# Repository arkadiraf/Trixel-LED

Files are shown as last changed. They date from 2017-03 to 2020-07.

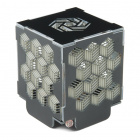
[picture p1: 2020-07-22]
Bootloader/SparkFun ISP Pogo Adapter - KIT-11591 - SparkFun Electronics_files/14638-Night_Light_Soldering_Kit-Built_.jpg

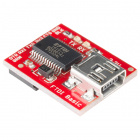
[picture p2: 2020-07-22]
Bootloader/SparkFun ISP Pogo Adapter - KIT-11591 - SparkFun Electronics_files/09873-01a.jpg

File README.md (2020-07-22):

# Trixel-LED
Trixel LED is an interactive LED kit,
Create your own interactive Light elements by soldering basic shapes, such as triangle, square, pentagon and Hexagon. to create an interactive LED sculpture.

### [Trixel LED on Hackaday](https://hackaday.io/project/20510-trixel-led)

<br /><span xmlns:dct="http://purl.org/dc/terms/" property="dct:title">Trixel-LED</span> is licensed under a <a rel="license" href="http://creativecommons.org/licenses/by-nc-sa/4.0/">Creative Commons Attribution-NonCommercial-ShareAlike 4.0 International License</a>.

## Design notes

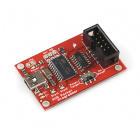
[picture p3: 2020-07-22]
Bootloader/SparkFun ISP Pogo Adapter - KIT-11591 - SparkFun Electronics_files/09825-01b.jpg

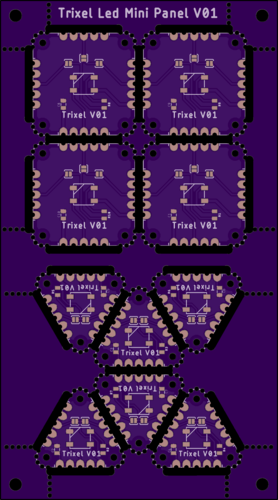
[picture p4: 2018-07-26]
Eagle/Single Side/Paneling/MiniPanel V01/design versions - temp/Top_V3.png

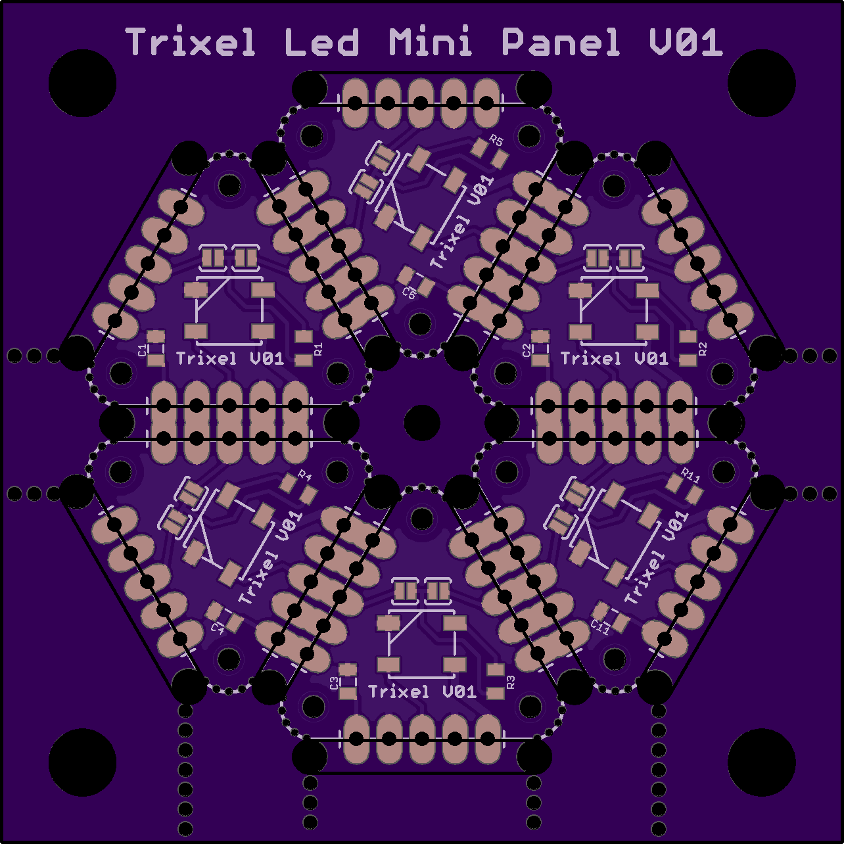
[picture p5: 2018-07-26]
Eagle/Single Side/Paneling/MiniPanel V01/design versions - temp/MiniPanel V01 Top.png

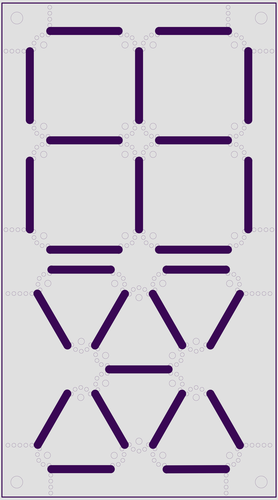
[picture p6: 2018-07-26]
Eagle/Single Side/Paneling/MiniPanel V01/design versions - temp/Border_V3.png

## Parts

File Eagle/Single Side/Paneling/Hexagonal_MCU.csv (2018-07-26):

 | Digikey | http://www.digikey.co.il/short/jzmwtr
Qty | Value | Device | Package | Parts | Description
2 | 0.1uF | CAP0805 | 805 | C1, C3 | Capacitor
1 | 10K | RESISTOR0805-RES | 805 | R2 | Resistor
4 | 10uF | CAP_POL1206 | EIA3216 | C7, C8, C9, C13 | Capacitor Polarized
1 | 16MHz | CRYSTALHC49US | HC49US | Y1 | Crystals
6 | 1k | RESISTOR0805-RES | 805 | R1, R3, R4, R6, R8, R9 | Resistor
2 | 1uF | CAP0805 | 805 | C5, C10 | Capacitor
2 | 22R | RESISTOR0805-RES | 805 | R5, R7 | Resistor
2 | 22pF | CAP0805 | 805 | C2, C4 | Capacitor
1 | ATMEGA32U4TQFP-44 | ATMEGA32U4TQFP-44 | TQFP44 | ATMEGA32U4 | Atmel 44-pin 8-bit Microcontroller with 32KBytes of ISP Flash and USB Controller
1 | B3U-1000P-2P-SMD | SMD-BUTTON(2P-4.0X3.0X1.5+0.5MM)SW-TS-017A-2P | SW2-4.0X3.0X2.0 | RESET | 311020047
1 | GREEN-0805 | SMD-LED-CLEAR-GREEN(0805) | LED-0805 | D1 | 304090057
1 | USB-MINIB-5PIN | USB-MINIB-5PIN | USB-MINIB | J3 | Mini-USB "B" connector with 5th pin broken out.

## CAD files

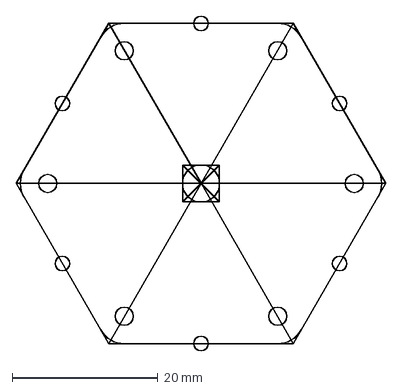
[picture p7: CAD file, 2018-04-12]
Eagle/Single Side/Hexagonal_MCU/Hexagonal_MCU_V01/Hexagonal_MCU.dxf
50.8 x 46.0 mm

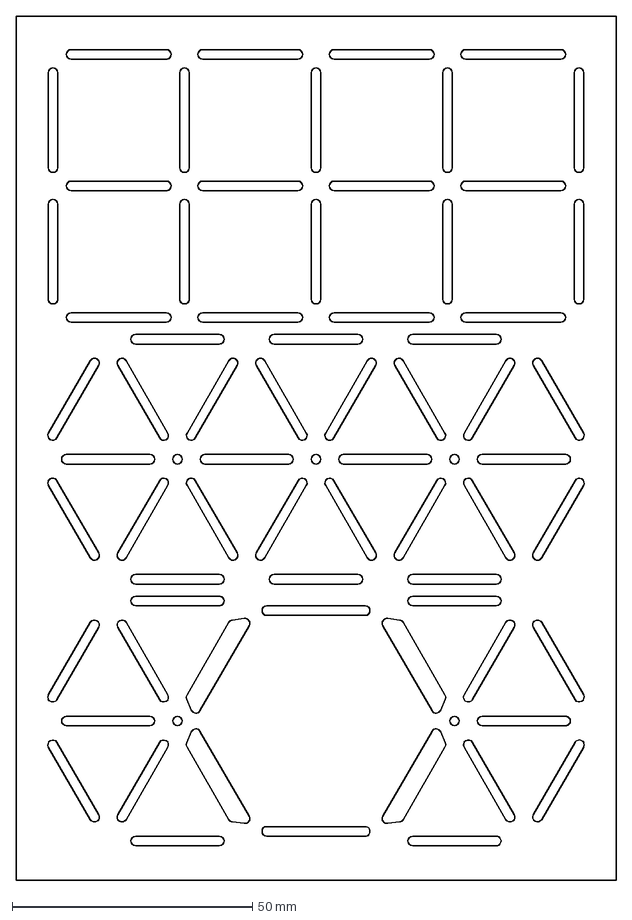
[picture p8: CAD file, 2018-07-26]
Eagle/Single Side/Paneling/LargePanel_V01/Backup_26_5_2018/LargePanel_V01.dxf
125.0 x 180.0 mm

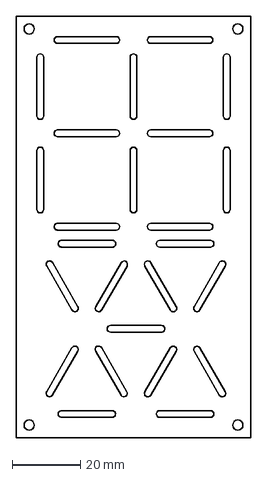
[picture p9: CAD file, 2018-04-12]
Eagle/Single Side/Paneling/MiniPanel V01/design versions - temp/Mini Panel V01.dxf
68.8 x 123.8 mm

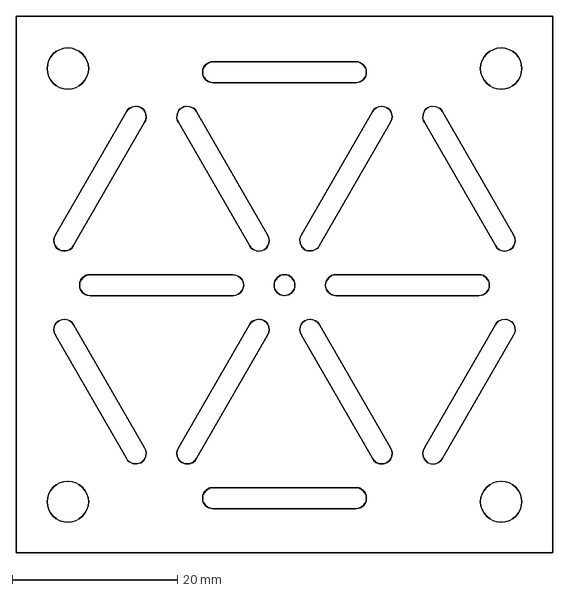
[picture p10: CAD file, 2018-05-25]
Eagle/Single Side/Paneling/MiniPanel V01/Trixel_MiniPanel_V01.dxf
65.0 x 65.0 mm

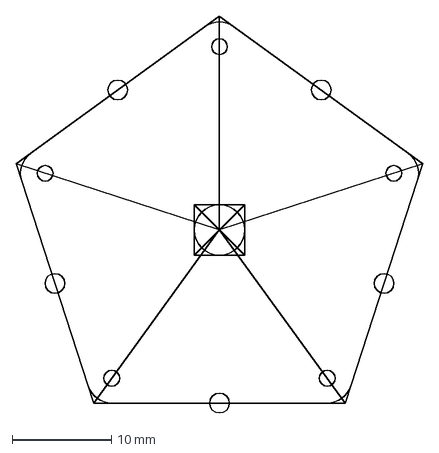
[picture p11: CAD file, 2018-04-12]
Eagle/Single Side/pentagon/Pentagon_V01/Pentagon_DXF.dxf
41.1 x 40.1 mm

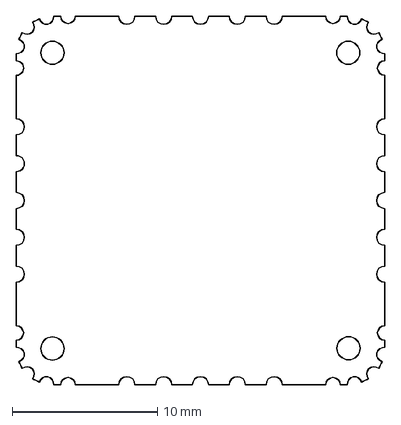
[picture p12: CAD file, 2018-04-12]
Eagle/Single Side/Sqaure/Square_V01/Trixel Square V01.dxf
25.4 x 25.4 mm

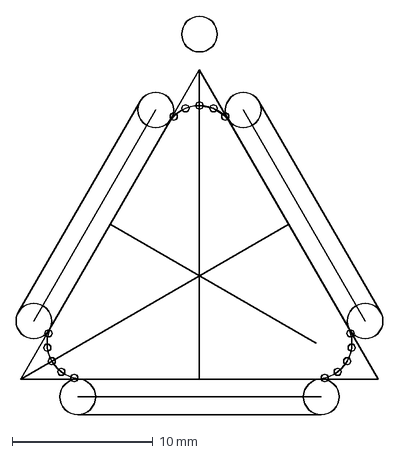
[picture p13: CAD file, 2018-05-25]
Eagle/Single Side/Triangle/Triangle_V01/Inches_Version/StampHoles_Trixel_V01.dxf
26.1 x 28.3 mm

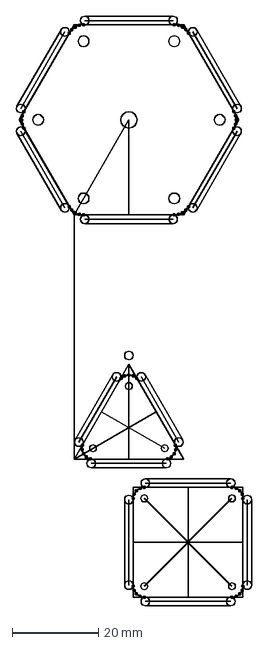
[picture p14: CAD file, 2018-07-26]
Eagle/Single Side/Triangle/Triangle_V01/Trixel_StampHoles.dxf
54.4 x 136.5 mm

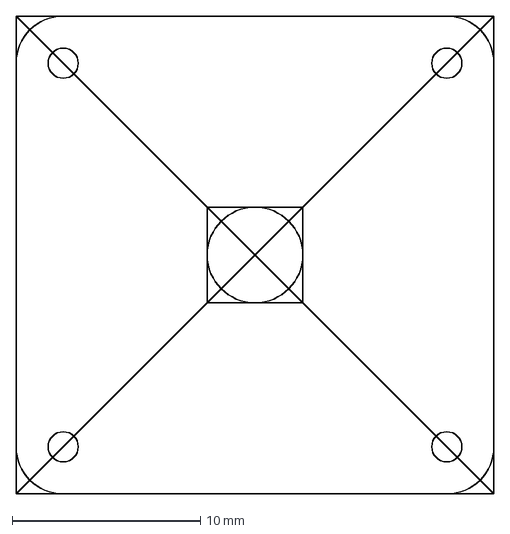
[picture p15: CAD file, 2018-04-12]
Eagle/Single Side/Sqaure/Square_V01/Square_DXF.dxf
25.4 x 25.4 mm

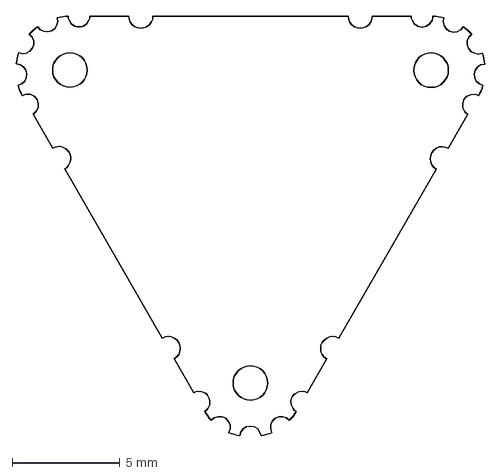
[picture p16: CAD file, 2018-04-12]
Eagle/Single Side/Triangle/Triangle_V01/Inches_Version/Trixel Triangle V01.dxf
21.7 x 19.4 mm

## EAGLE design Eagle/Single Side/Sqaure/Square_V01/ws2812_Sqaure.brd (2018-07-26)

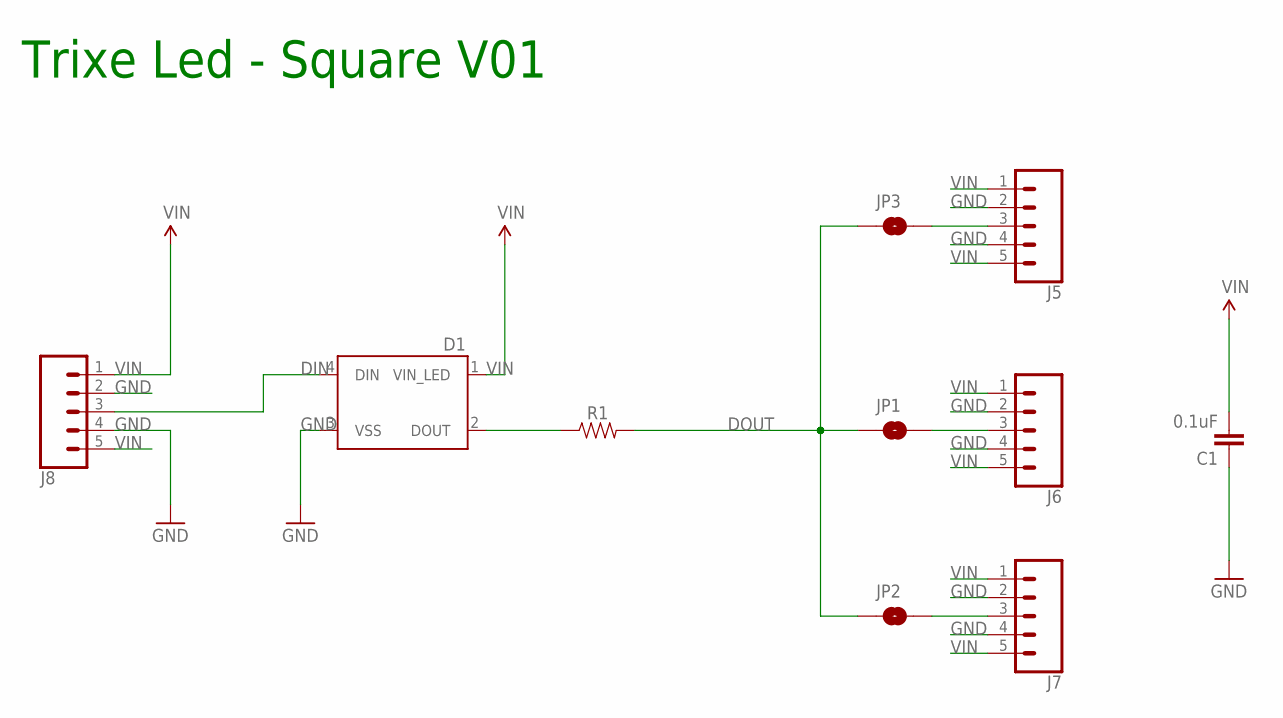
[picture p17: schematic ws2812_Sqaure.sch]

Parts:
C1: 0.1uF; 0805
D1: WS2812B
J5, J6, J7, J8: CONN_05PTH_LONGPADS; 1X05_LONGPADS
JP1, JP2, JP3: JUMPER-PAD-2-NOYES_SILK; PAD-JUMPER-2-NO_YES_SILK
R1: 0805

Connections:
DIN: D1.4 (DIN), J8.3
DOUT: JP1.1, JP2.1, JP3.1, R1.2
GND: C1.1, D1.3 (VSS), J5.2, J5.4, J6.2, J6.4, J7.2, J7.4, J8.2, J8.4
unnamed: J7.3, JP2.2
unnamed: J6.3, JP1.2
unnamed: J5.3, JP3.2
unnamed: D1.2 (DOUT), R1.1
VIN: C1.2, D1.1 (VIN_LED), J5.1, J5.5, J6.1, J6.5, J7.1, J7.5, J8.1, J8.5

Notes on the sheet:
Trixe Led - Square V01

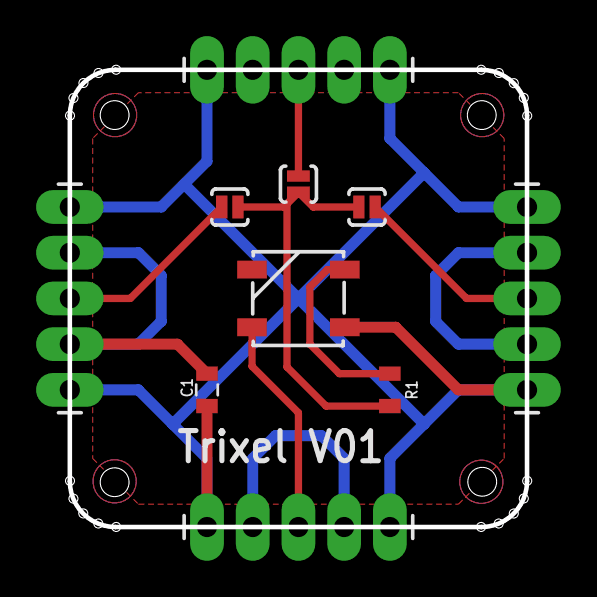
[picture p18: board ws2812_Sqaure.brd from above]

Board: 2 copper layers, 25.4 x 25.4 mm, 10 parts (0 on the bottom side), 8 nets.

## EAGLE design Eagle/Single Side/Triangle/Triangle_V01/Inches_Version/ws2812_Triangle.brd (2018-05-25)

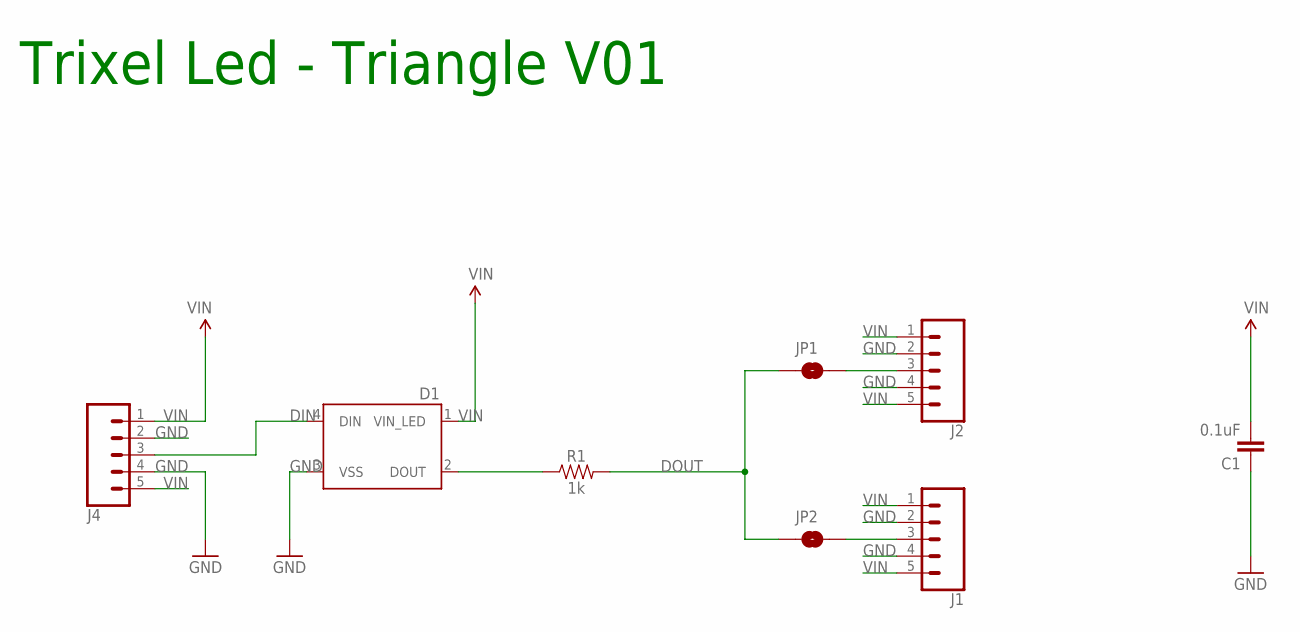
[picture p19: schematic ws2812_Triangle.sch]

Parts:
C1: 0.1uF; 0805
D1: WS2812B
J1, J2, J4: CONN_05PTH_LONGPADS; 1X05_LONGPADS
JP1, JP2: JUMPER-PAD-2-NOYES_SILK; PAD-JUMPER-2-NO_YES_SILK
R1: 1k; 0805

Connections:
DIN: D1.4 (DIN), J4.3
DOUT: JP1.1, JP2.1, R1.2
GND: C1.1, D1.3 (VSS), J1.2, J1.4, J2.2, J2.4, J4.2, J4.4
unnamed: J1.3, JP2.2
unnamed: J2.3, JP1.2
unnamed: D1.2 (DOUT), R1.1
VIN: C1.2, D1.1 (VIN_LED), J1.1, J1.5, J2.1, J2.5, J4.1, J4.5

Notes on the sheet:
Trixel Led - Triangle V01

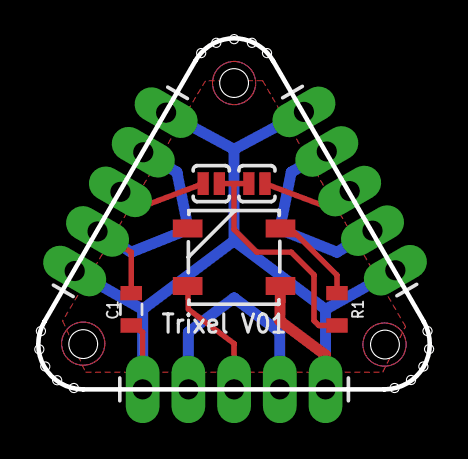
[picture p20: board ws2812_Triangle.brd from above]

Board: 2 copper layers, 21.7 x 19.5 mm, 8 parts (0 on the bottom side), 7 nets.

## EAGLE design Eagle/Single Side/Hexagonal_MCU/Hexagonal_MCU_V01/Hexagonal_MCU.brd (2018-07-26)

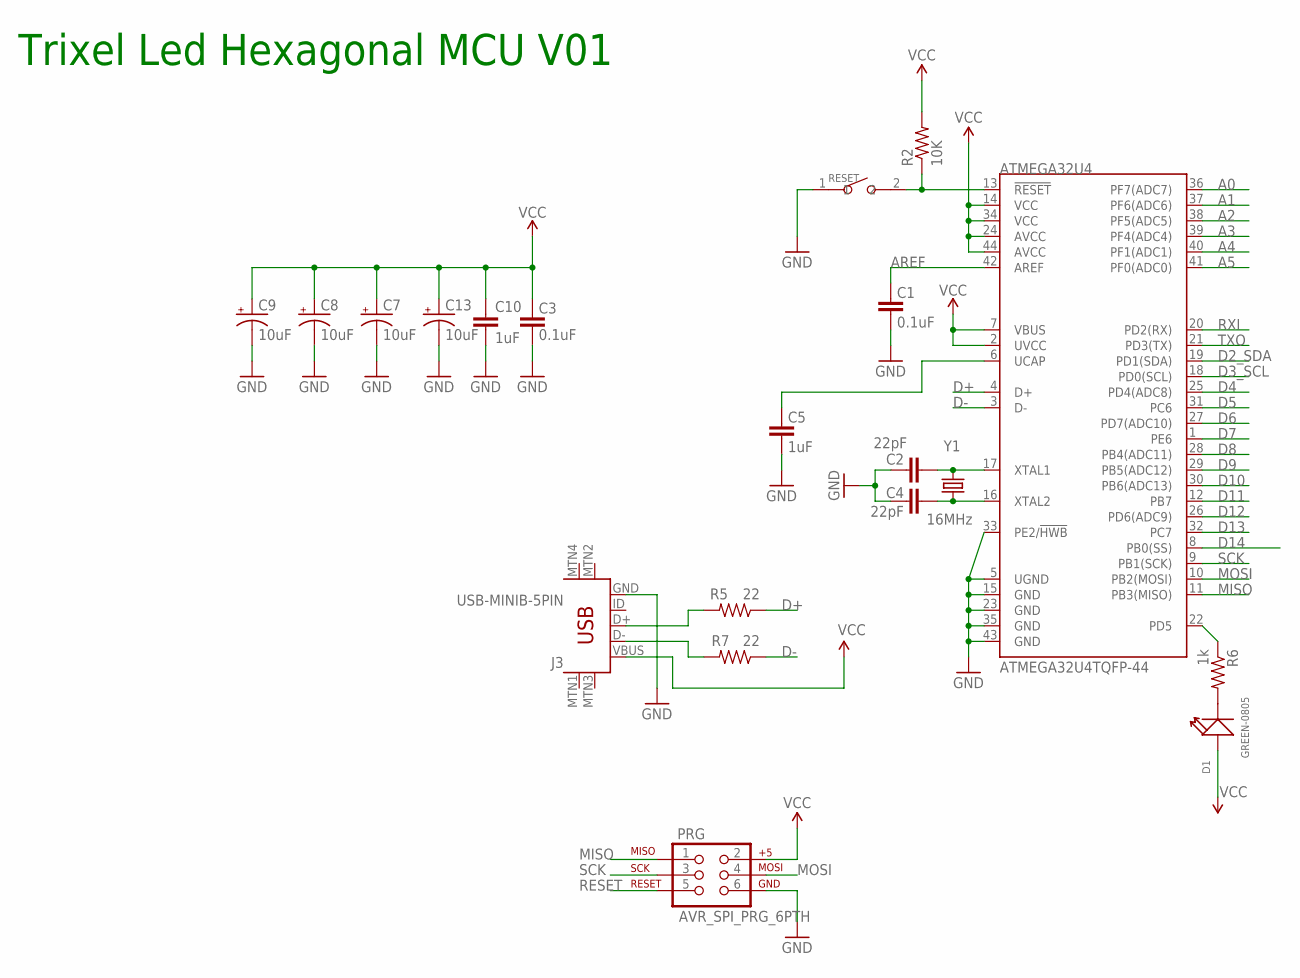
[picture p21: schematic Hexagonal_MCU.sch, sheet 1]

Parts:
ATMEGA32U4: ATMEGA32U4TQFP-44; TQFP44
C1, C3: 0.1uF; 0805
C2, C4: 22pF; 0805
C5, C10: 1uF; 0805
C7, C8, C9, C13: 10uF; EIA3216
D1: GREEN-0805; LED-0805
J3: USB-MINIB-5PIN; USB-MINIB
PRG: AVR_SPI_PRG_6PTH; 2X3
R2: 10K; 0805
R5, R7: 22; 0805
R6: 1k; 0805
RESET: B3U-1000P-2P-SMD; SW2-4.0X3.0X2.0
Y1: 16MHz; HC49US

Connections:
5V: ATMEGA32U4.2 (UVCC), ATMEGA32U4.7 (VBUS), ATMEGA32U4.14 (VCC), ATMEGA32U4.24 (AVCC), ATMEGA32U4.34 (VCC), ATMEGA32U4.44 (AVCC), C3.2, C7.A (+), C8.A (+), C9.A (+), C10.1, C13.A (+), D1.+, J3.VBUS, PRG.2, R2.2; also elsewhere on the board
A0: ATMEGA32U4.36 (PF7(ADC7))
A1: ATMEGA32U4.37 (PF6(ADC6))
A2: ATMEGA32U4.38 (PF5(ADC5))
A3: ATMEGA32U4.39 (PF4(ADC4))
A4: ATMEGA32U4.40 (PF1(ADC1))
A5: ATMEGA32U4.41 (PF0(ADC0))
AREF: ATMEGA32U4.42 (AREF), C1.2
D2_SDA: ATMEGA32U4.19 (PD1(SDA)); also elsewhere on the board
D3_SCL: ATMEGA32U4.18 (PD0(SCL))
D4: ATMEGA32U4.25 (PD4(ADC8))
D5: ATMEGA32U4.31 (PC6); also elsewhere on the board
D6: ATMEGA32U4.27 (PD7(ADC10))
D7: ATMEGA32U4.1 (PE6); also elsewhere on the board
D8: ATMEGA32U4.28 (PB4(ADC11)); also elsewhere on the board
D9: ATMEGA32U4.29 (PB5(ADC12))
D10: ATMEGA32U4.30 (PB6(ADC13))
D11: ATMEGA32U4.12 (PB7); also elsewhere on the board
D12: ATMEGA32U4.26 (PD6(ADC9))
D13: ATMEGA32U4.32 (PC7)
D14: ATMEGA32U4.8 (PB0(SS))
D+: ATMEGA32U4.4 (D+), R5.1
D-: ATMEGA32U4.3 (D-), R7.1
GND: ATMEGA32U4.5 (UGND), ATMEGA32U4.15 (GND), ATMEGA32U4.23 (GND), ATMEGA32U4.33 (PE2/!HWB), ATMEGA32U4.35 (GND), ATMEGA32U4.43 (GND), C1.1, C2.2, C3.1, C4.2, C5.1, C7.C (-), C8.C (-), C9.C (-), C10.2, C13.C (-), J3.GND, PRG.6, RESET.1; also elsewhere on the board
MISO: ATMEGA32U4.11 (PB3(MISO)), PRG.1
MOSI: ATMEGA32U4.10 (PB2(MOSI)), PRG.4
unnamed: ATMEGA32U4.16 (XTAL2), C4.1, Y1.1
unnamed: ATMEGA32U4.17 (XTAL1), C2.1, Y1.2
unnamed: J3.D-, R7.2
unnamed: D1.-, R6.2
unnamed: J3.D+, R5.2
RESET: ATMEGA32U4.13 (!RESET), PRG.5, R2.1, RESET.2
RXI: ATMEGA32U4.20 (PD2(RX))
SCK: ATMEGA32U4.9 (PB1(SCK)), PRG.3
TXLED: ATMEGA32U4.22 (PD5), R6.1
TXO: ATMEGA32U4.21 (PD3(TX))
UCAP: ATMEGA32U4.6 (UCAP), C5.2

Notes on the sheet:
Trixel Led Hexagonal MCU V01

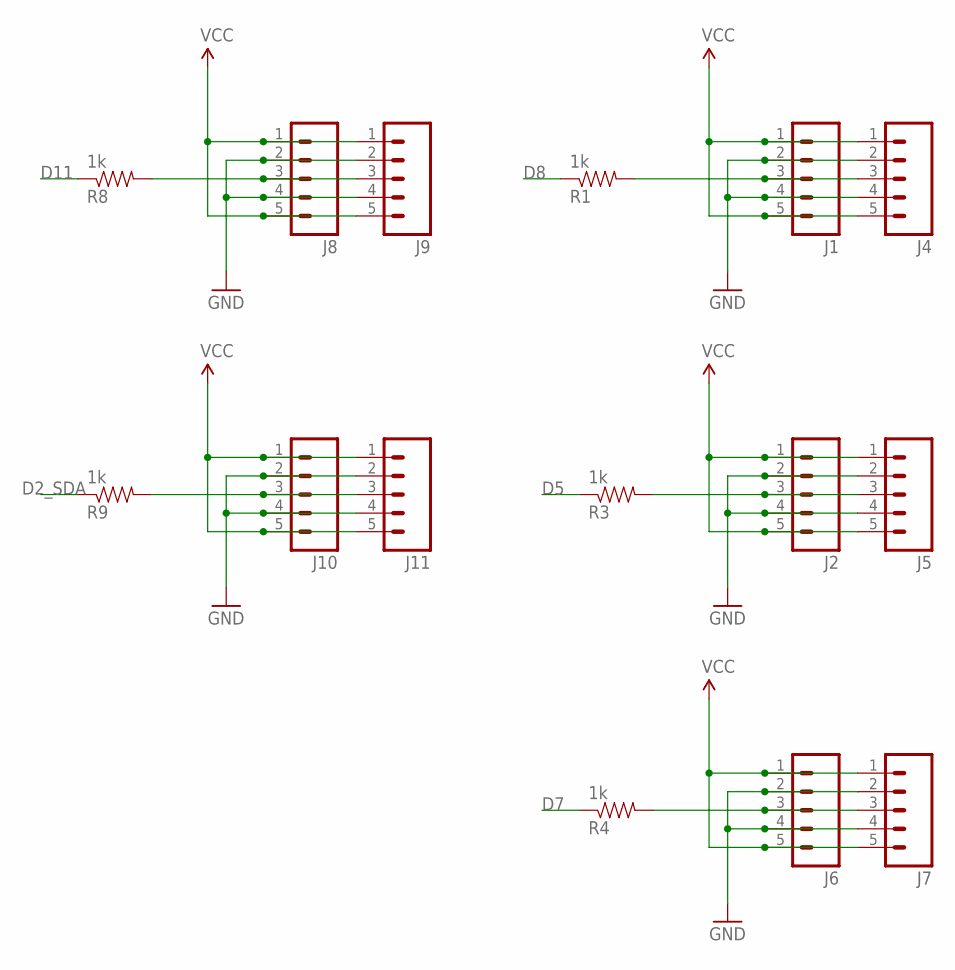
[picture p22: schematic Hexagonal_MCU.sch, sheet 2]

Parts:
J1, J2, J6, J8, J10: M05NO_SILK; 1X05_NO_SILK
J4, J5, J7, J9, J11: M05PTH_LONGPADS; 1X05_LONGPADS
R1, R3, R4, R8, R9: 1k; 0805

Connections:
5V: J1.1, J1.5, J2.1, J2.5, J4.1, J4.5, J5.1, J5.5, J6.1, J6.5, J7.1, J7.5, J8.1, J8.5, J9.1, J9.5, J10.1, J10.5, J11.1, J11.5; also elsewhere on the board
D2_SDA: R9.1; also elsewhere on the board
D5: R3.1; also elsewhere on the board
D7: R4.1; also elsewhere on the board
D8: R1.1; also elsewhere on the board
D11: R8.1; also elsewhere on the board
GND: J1.2, J1.4, J2.2, J2.4, J4.2, J4.4, J5.2, J5.4, J6.2, J6.4, J7.2, J7.4, J8.2, J8.4, J9.2, J9.4, J10.2, J10.4, J11.2, J11.4; also elsewhere on the board
unnamed: J2.3, J5.3, R3.2
unnamed: J1.3, J4.3, R1.2
unnamed: J6.3, J7.3, R4.2
unnamed: J8.3, J9.3, R8.2
unnamed: J10.3, J11.3, R9.2

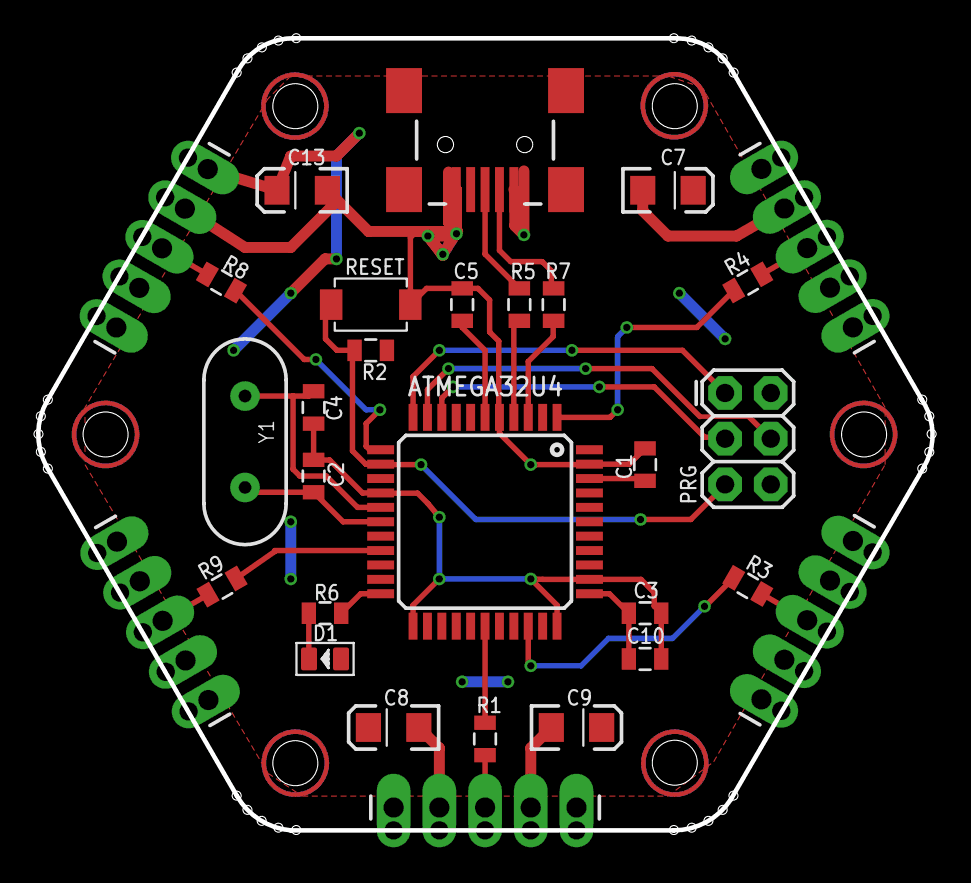
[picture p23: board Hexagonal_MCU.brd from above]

Board: 2 copper layers, 49.7 x 44.0 mm, 35 parts (0 on the bottom side), 26 nets.

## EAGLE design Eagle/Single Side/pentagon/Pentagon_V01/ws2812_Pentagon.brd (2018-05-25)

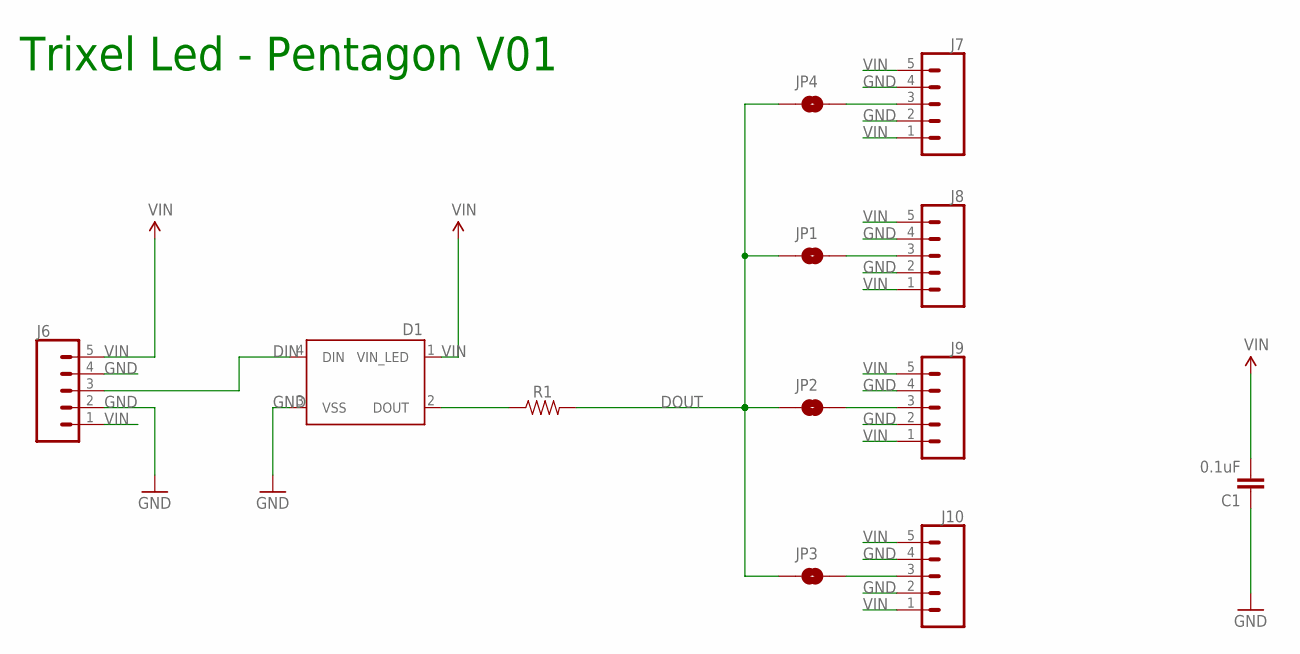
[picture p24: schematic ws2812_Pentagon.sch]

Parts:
C1: 0.1uF; 0805
D1: WS2812B
J6, J7, J8, J9, J10: CONN_05PTH_LONGPADS; 1X05_LONGPADS
JP1, JP2, JP3, JP4: JUMPER-PAD-2-NOYES_SILK; PAD-JUMPER-2-NO_YES_SILK
R1: 0805

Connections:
DIN: D1.4 (DIN), J6.3
DOUT: JP1.1, JP2.1, JP3.1, JP4.1, R1.2
GND: C1.1, D1.3 (VSS), J6.2, J6.4, J7.2, J7.4, J8.2, J8.4, J9.2, J9.4, J10.2, J10.4
unnamed: J9.3, JP2.2
unnamed: J8.3, JP1.2
unnamed: D1.2 (DOUT), R1.1
unnamed: J7.3, JP4.2
unnamed: J10.3, JP3.2
VIN: C1.2, D1.1 (VIN_LED), J6.1, J6.5, J7.1, J7.5, J8.1, J8.5, J9.1, J9.5, J10.1, J10.5

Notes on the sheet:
Trixel Led - Pentagon V01

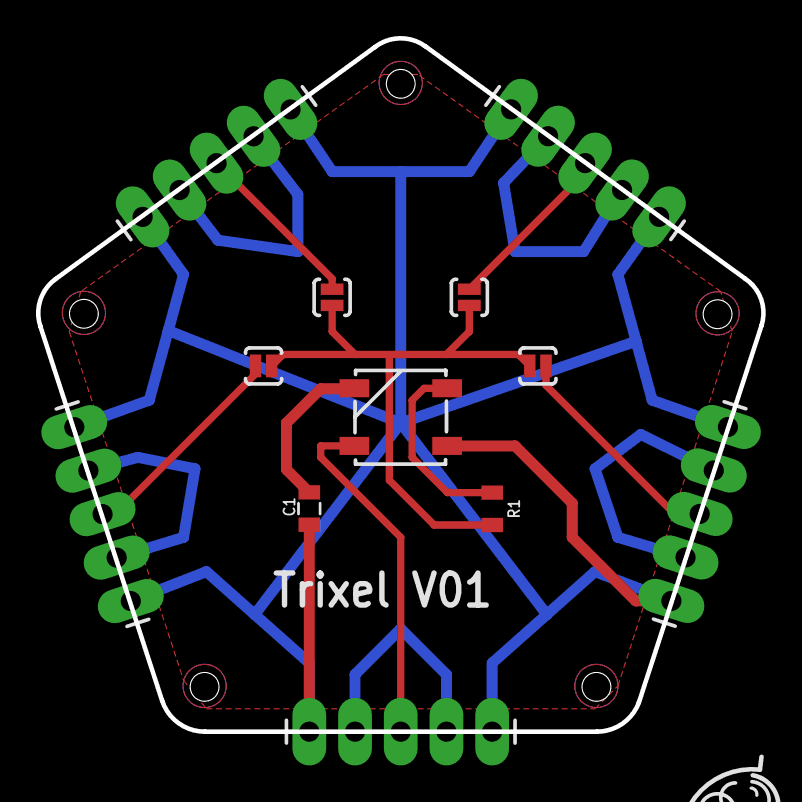
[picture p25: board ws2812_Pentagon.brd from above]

Board: 2 copper layers, 40.3 x 38.5 mm, 12 parts (0 on the bottom side), 9 nets.

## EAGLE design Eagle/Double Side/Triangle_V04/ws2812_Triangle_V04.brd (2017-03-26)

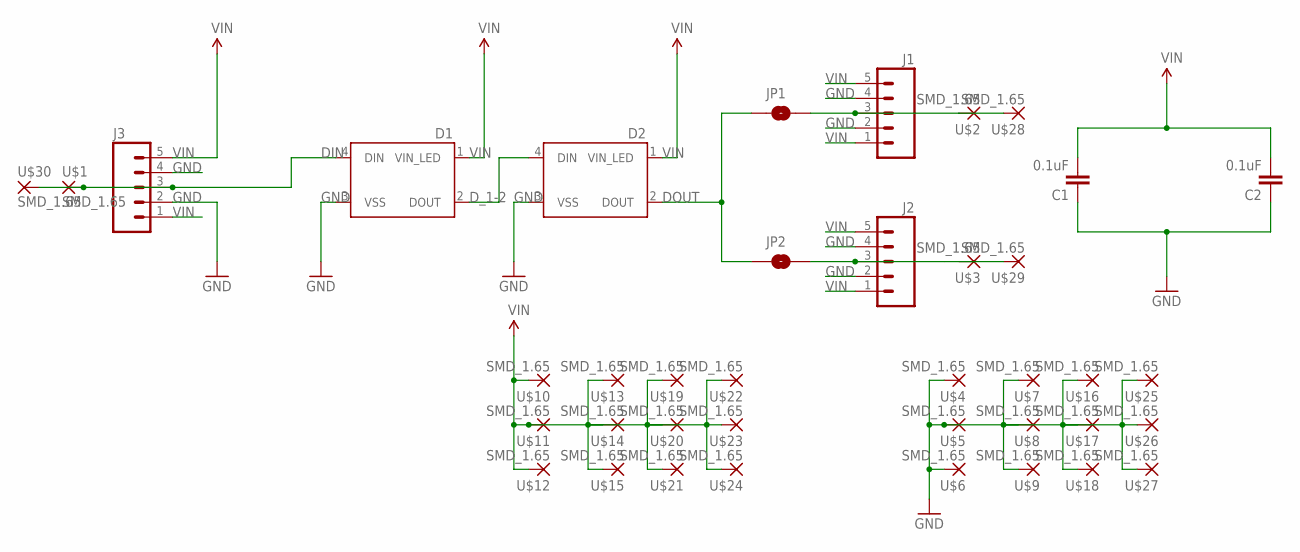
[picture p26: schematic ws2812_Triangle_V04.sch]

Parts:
C1, C2: 0.1uF; 0805
D1, D2: WS2812B
J1, J2, J3: M05NO_SILK; 1X05_NO_SILK
JP1, JP2: JUMPER-PAD-2-NOYES_SILK; PAD-JUMPER-2-NO_YES_SILK
U$1, U$2, U$3, U$4, U$5, U$6, U$7, U$8, U$9, U$10, U$11, U$12, U$13, U$14, U$15, U$16, U$17, U$18, U$19, U$20, U$21, U$22, U$23, U$24, U$25, U$26, U$27, U$28, U$29, U$30: SMD_1.65; SMD_PTH_1.65

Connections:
DIN: D1.4 (DIN), J3.3, U$1.P$1, U$30.P$1
DOUT: D2.2 (DOUT), JP1.1, JP2.1
D_1-2: D1.2 (DOUT), D2.4 (DIN)
GND: C1.1, C2.1, D1.3 (VSS), D2.3 (VSS), J1.2, J1.4, J2.2, J2.4, J3.2, J3.4, U$4.P$1, U$5.P$1, U$6.P$1, U$7.P$1, U$8.P$1, U$9.P$1, U$16.P$1, U$17.P$1, U$18.P$1, U$25.P$1, U$26.P$1, U$27.P$1
unnamed: J2.3, JP2.2, U$3.P$1, U$29.P$1
unnamed: J1.3, JP1.2, U$2.P$1, U$28.P$1
VIN: C1.2, C2.2, D1.1 (VIN_LED), D2.1 (VIN_LED), J1.1, J1.5, J2.1, J2.5, J3.1, J3.5, U$10.P$1, U$11.P$1, U$12.P$1, U$13.P$1, U$14.P$1, U$15.P$1, U$19.P$1, U$20.P$1, U$21.P$1, U$22.P$1, U$23.P$1, U$24.P$1

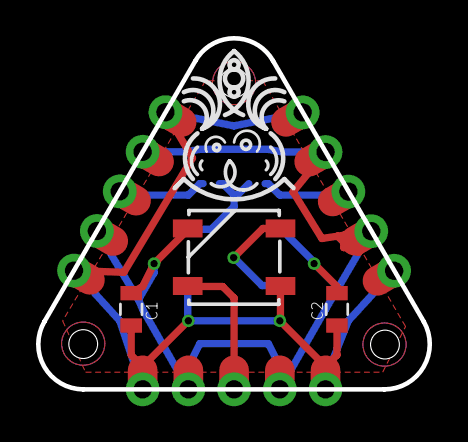
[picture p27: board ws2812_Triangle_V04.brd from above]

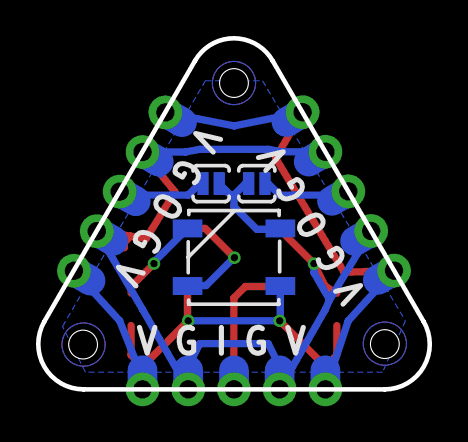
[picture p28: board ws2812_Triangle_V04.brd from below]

Board: 2 copper layers, 21.7 x 19.5 mm, 39 parts (18 on the bottom side), 7 nets.

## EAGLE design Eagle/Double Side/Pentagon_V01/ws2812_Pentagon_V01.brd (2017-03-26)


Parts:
C1, C2: 0.1uF; 0805
D1, D2: WS2812B
J1, J2, J3, J4, J5: M05NO_SILK; 1X05_NO_SILK
JP1, JP2, JP3, JP4: JUMPER-PAD-2-NOYES_SILK; PAD-JUMPER-2-NO_YES_SILK
U$1, U$2, U$3, U$4, U$5, U$6, U$7, U$8, U$9, U$10, U$11, U$12, U$13, U$14, U$15, U$16, U$17, U$18, U$19, U$20, U$21, U$22, U$23, U$24, U$25, U$26, U$27, U$28, U$29, U$30, U$31, U$32, U$33, U$34, U$35, U$36, U$37, U$38, U$39, U$40, U$41, U$42, U$43, U$44, U$45, U$46, U$47, U$48, U$49, U$50: SMD_1.65; SMD_PTH_1.65

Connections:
DIN: D1.4 (DIN), J3.3, U$1.P$1, U$30.P$1
DOUT1: D2.2 (DOUT), JP1.1, JP2.1, JP3.1, JP4.1
D_1-2: D1.2 (DOUT), D2.4 (DIN)
GND: C1.1, C2.1, D1.3 (VSS), D2.3 (VSS), J1.2, J1.4, J2.2, J2.4, J3.2, J3.4, J4.2, J4.4, J5.2, J5.4, U$4.P$1, U$5.P$1, U$6.P$1, U$7.P$1, U$8.P$1, U$9.P$1, U$16.P$1, U$17.P$1, U$18.P$1, U$25.P$1, U$26.P$1, U$27.P$1, U$37.P$1, U$38.P$1, U$39.P$1, U$40.P$1, U$47.P$1, U$48.P$1, U$49.P$1, U$50.P$1
unnamed: J4.3, JP1.2
unnamed: J2.3, JP3.2
unnamed: J1.3, JP2.2
unnamed: J5.3, JP4.2
VIN: C1.2, C2.2, D1.1 (VIN_LED), D2.1 (VIN_LED), J1.1, J1.5, J2.1, J2.5, J3.1, J3.5, J4.1, J4.5, J5.1, J5.5, U$10.P$1, U$11.P$1, U$12.P$1, U$13.P$1, U$14.P$1, U$15.P$1, U$19.P$1, U$20.P$1, U$21.P$1, U$22.P$1, U$23.P$1, U$24.P$1, U$33.P$1, U$34.P$1, U$35.P$1, U$36.P$1, U$43.P$1, U$44.P$1, U$45.P$1, U$46.P$1



Board: 2 copper layers, 40.3 x 38.5 mm, 63 parts (30 on the bottom side), 9 nets.

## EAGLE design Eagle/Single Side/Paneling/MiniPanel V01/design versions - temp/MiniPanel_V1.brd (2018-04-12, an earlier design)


Board: 2 copper layers, 68.8 x 123.8 mm, 88 parts (0 on the bottom side), 74 nets.

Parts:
C1, C2, C3, C4, C5, C6, C7, C8, C9, C10: 0.1uF; 0805
D1, D2, D3, D4, D5, D6, D7, D8, D9, D10: WS2812B
J1, J2, J3, J4, J5, J6, J7, J8, J9, J10, J11, J12, J13, J14, J15, J16, J17, J18, J19, J20, J21, J22, J23, J24, J25, J26, J27, J28, J29, J30, J31, J32, J33, J34: 1X05_LONGPADS
JP1, JP2, JP3, JP4, JP5, JP6, JP7, JP8, JP9, JP10, JP11, JP12, JP13, JP14, JP15, JP16, JP17, JP18, JP19, JP20, JP21, JP22, JP23, JP24: JUMPER-PAD-2-NOYES_SILK; PAD-JUMPER-2-NO_YES_SILK
R1, R8, R9, R10: 0805
R2, R3, R4, R5, R6, R7: 1k; 0805

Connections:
DIN: D1.4, J22.3
DIN1: D2.4, J3.3
DIN2: D3.4, J7.3
DIN3: D4.4, J10.3
DIN4: D5.4, J13.3
DIN5: D6.4, J16.3
DIN6: D7.4, J19.3
DIN7: D8.4, J26.3
DIN8: D9.4, J30.3
DIN9: D10.4, J34.3
DOUT: JP1.1, JP2.1, JP15.1, R1.2
DOUT1: JP3.1, JP4.1, R2.2
DOUT2: JP5.1, JP6.1, R3.2
DOUT3: JP7.1, JP8.1, R4.2
DOUT4: JP9.1, JP10.1, R5.2
DOUT5: JP11.1, JP12.1, R6.2
DOUT6: JP13.1, JP14.1, R7.2
DOUT7: JP16.1, JP17.1, JP18.1, R8.2
DOUT8: JP19.1, JP20.1, JP21.1, R9.2
DOUT9: JP22.1, JP23.1, JP24.1, R10.2
GND: C1.1, D1.3, J1.2, J1.4, J2.2, J2.4, J4.2, J4.4, J22.2, J22.4
GND1: C2.1, D2.3, J3.2, J3.4, J5.2, J5.4, J6.2, J6.4
GND2: C3.1, D3.3, J7.2, J7.4, J8.2, J8.4, J9.2, J9.4
GND3: C4.1, D4.3, J10.2, J10.4, J11.2, J11.4, J12.2, J12.4
GND4: C5.1, D5.3, J13.2, J13.4, J14.2, J14.4, J15.2, J15.4
GND5: C6.1, D6.3, J16.2, J16.4, J17.2, J17.4, J18.2, J18.4
GND6: C7.1, D7.3, J19.2, J19.4, J20.2, J20.4, J21.2, J21.4
GND7: C8.1, D8.3, J23.2, J23.4, J24.2, J24.4, J25.2, J25.4, J26.2, J26.4
GND8: C9.1, D9.3, J27.2, J27.4, J28.2, J28.4, J29.2, J29.4, J30.2, J30.4
GND9: C10.1, D10.3, J31.2, J31.4, J32.2, J32.4, J33.2, J33.4, J34.2, J34.4
unnamed: J4.3, JP2.2
unnamed: J2.3, JP1.2
unnamed: J1.3, JP15.2
unnamed: J5.3, JP4.2
unnamed: D2.2, R2.1
unnamed: J6.3, JP3.2
unnamed: J8.3, JP6.2
unnamed: D3.2, R3.1
unnamed: J9.3, JP5.2
unnamed: J11.3, JP8.2
unnamed: D4.2, R4.1
unnamed: J12.3, JP7.2
unnamed: J14.3, JP10.2
unnamed: D5.2, R5.1
unnamed: J15.3, JP9.2
unnamed: J17.3, JP12.2
unnamed: D6.2, R6.1
unnamed: J18.3, JP11.2
unnamed: J20.3, JP14.2
unnamed: D7.2, R7.1
unnamed: J21.3, JP13.2
unnamed: D1.2, R1.1
unnamed: J25.3, JP17.2
unnamed: J24.3, JP16.2
unnamed: J23.3, JP18.2
unnamed: D8.2, R8.1
unnamed: J29.3, JP20.2
unnamed: J28.3, JP19.2
unnamed: J27.3, JP21.2
unnamed: D9.2, R9.1
unnamed: J33.3, JP23.2
unnamed: J32.3, JP22.2
unnamed: J31.3, JP24.2
unnamed: D10.2, R10.1
VIN: C1.2, D1.1, J1.1, J1.5, J2.1, J2.5, J4.1, J4.5, J22.1, J22.5
VIN1: C2.2, D2.1, J3.1, J3.5, J5.1, J5.5, J6.1, J6.5
VIN2: C3.2, D3.1, J7.1, J7.5, J8.1, J8.5, J9.1, J9.5
VIN3: C4.2, D4.1, J10.1, J10.5, J11.1, J11.5, J12.1, J12.5
VIN4: C5.2, D5.1, J13.1, J13.5, J14.1, J14.5, J15.1, J15.5
VIN5: C6.2, D6.1, J16.1, J16.5, J17.1, J17.5, J18.1, J18.5
VIN6: C7.2, D7.1, J19.1, J19.5, J20.1, J20.5, J21.1, J21.5
VIN7: C8.2, D8.1, J23.1, J23.5, J24.1, J24.5, J25.1, J25.5, J26.1, J26.5
VIN8: C9.2, D9.1, J27.1, J27.5, J28.1, J28.5, J29.1, J29.5, J30.1, J30.5
VIN9: C10.2, D10.1, J31.1, J31.5, J32.1, J32.5, J33.1, J33.5, J34.1, J34.5

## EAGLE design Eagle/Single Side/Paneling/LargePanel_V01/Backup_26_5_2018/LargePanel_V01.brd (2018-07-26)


Board: 2 copper layers, 125.0 x 180.0 mm, 291 parts (0 on the bottom side), 244 nets.

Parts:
ATMEGA32U4: ATMEGA32U4TQFP-44; TQFP44
C1, C2, C3, C4, C12, C14, C15, C16, C17, C18, C19, C20, C21, C22, C23, C24, C25, C26, C27, C28, C29, C30, C31, C32, C33, C34, C35, C36, C37, C38, C39, C40: 0.1uF; 0805
C5, C6: 22pF; 0805
C7, C10: 1uF; 0805
C8, C9, C11, C13: 10uF; EIA3216
D1, D2, D4, D5, D6, D7, D8, D9, D10, D11, D12, D13, D14, D15, D16, D17, D18, D19, D20, D21, D22, D23, D24, D25, D26, D27, D28, D29, D30, D31: WS2812B
D3: GREEN-0805; LED-0805
J1, J2, J4, J5, J6, J7, J8, J10, J12, J14, J16, J18, J19, J20, J21, J22, J23, J24, J25, J26, J27, J28, J29, J30, J31, J32, J33, J34, J35, J36, J37, J38, J39, J40, J41, J42, J43, J44, J45, J46, J47, J48, J49, J50, J51, J52, J53, J54, J55, J56, J57, J58, J59, J60, J61, J62, J63, J64, J65, J66, J67, J68, J69, J70, J71, J72, J73, J74, J75, J76, J77, J78, J79, J80, J81, J82, J83, J84, J85, J86, J87, J88, J89, J90, J91, J92, J93, J94, J95, J96, J97, J98, J99, J100, J101, J102, J103, J104, J105, J106, J107, J108, J109: 1X05_LONGPADS
J3: USB-MINIB-5PIN; USB-MINIB
J9, J11, J13, J15, J17: 1X05_NO_SILK
JP1, JP2, JP3, JP4, JP5, JP6, JP7, JP8, JP9, JP10, JP11, JP12, JP13, JP14, JP15, JP16, JP17, JP18, JP19, JP20, JP21, JP22, JP23, JP24, JP25, JP26, JP27, JP28, JP29, JP30, JP31, JP32, JP33, JP34, JP35, JP36, JP37, JP38, JP39, JP40, JP41, JP42, JP43, JP44, JP45, JP46, JP47, JP48, JP49, JP50, JP51, JP52, JP53, JP54, JP55, JP56, JP57, JP58, JP59, JP60, JP61, JP62, JP63, JP64, JP65, JP66, JP67, JP68: JUMPER-PAD-2-NOYES_SILK; PAD-JUMPER-2-NO_YES_SILK
PRG: AVR_SPI_PRG_6PTH; 2X3
R1, R4, R6, R8, R9, R10, R11, R12, R13, R14, R15, R16, R17, R18, R19, R20, R21, R22, R23, R24, R25, R26, R27, R28, R29, R30, R31, R32: 1k; 0805
R2, R33, R34, R35, R36, R37, R38, R39: 0805
R3: 10K; 0805
R5, R7: 22; 0805
RESET: B3U-1000P-2P-SMD; SW2-4.0X3.0X2.0
Y1: 16MHz; HC49US

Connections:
5V: ATMEGA32U4.2, ATMEGA32U4.7, ATMEGA32U4.14, ATMEGA32U4.24, ATMEGA32U4.34, ATMEGA32U4.44, C3.2, C8.A, C9.A, C10.1, C11.A, C13.A, D3.+, J3.VBUS, J9.1, J9.5, J10.1, J10.5, J11.1, J11.5, J12.1, J12.5, J13.1, J13.5, J14.1, J14.5, J15.1, J15.5, J16.1, J16.5, J17.1, J17.5, J18.1, J18.5, PRG.2, R3.2
AREF: ATMEGA32U4.42, C4.2
D2_SDA: ATMEGA32U4.19, R11.1
D5: ATMEGA32U4.31, R8.1
D7: ATMEGA32U4.1, R9.1
D8: ATMEGA32U4.28, R4.1
D11: ATMEGA32U4.12, R10.1
D+: ATMEGA32U4.4, R5.1
D-: ATMEGA32U4.3, R7.1
DIN: D1.4, J4.3
DIN1: D2.4, J8.3
DIN2: D4.4, J19.3
DIN3: D5.4, J22.3
DIN4: D6.4, J25.3
DIN5: D7.4, J28.3
DIN6: D8.4, J31.3
DIN7: D9.4, J34.3
DIN8: D10.4, J37.3
DIN9: D11.4, J40.3
DIN10: D12.4, J43.3
DIN11: D13.4, J46.3
DIN12: D14.4, J49.3
DIN13: D15.4, J52.3
DIN14: D16.4, J55.3
DIN15: D17.4, J58.3
DIN16: D18.4, J61.3
DIN17: D19.4, J64.3
DIN18: D20.4, J67.3
DIN19: D21.4, J70.3
DIN20: D22.4, J73.3
DIN21: D23.4, J76.3
DIN22: D24.4, J79.3
DIN23: D25.4, J85.3
DIN24: D26.4, J89.3
DIN25: D27.4, J93.3
DIN26: D28.4, J97.3
DIN27: D29.4, J101.3
DIN28: D30.4, J105.3
DIN29: D31.4, J109.3
DOUT: JP1.1, JP2.1, R1.2
DOUT1: JP3.1, JP4.1, JP5.1, R2.2
DOUT2: JP6.1, JP7.1, R12.2
DOUT3: JP8.1, JP9.1, R13.2
DOUT4: JP10.1, JP11.1, R14.2
DOUT5: JP12.1, JP13.1, R15.2
DOUT6: JP14.1, JP15.1, R16.2
DOUT7: JP16.1, JP17.1, R17.2
DOUT8: JP18.1, JP19.1, R18.2
DOUT9: JP20.1, JP21.1, R19.2
DOUT10: JP22.1, JP23.1, R20.2
DOUT11: JP24.1, JP25.1, R21.2
DOUT12: JP26.1, JP27.1, R22.2
DOUT13: JP28.1, JP29.1, R23.2
DOUT14: JP30.1, JP31.1, R24.2
DOUT15: JP32.1, JP33.1, R25.2
DOUT16: JP34.1, JP35.1, R26.2
DOUT17: JP36.1, JP37.1, R27.2
DOUT18: JP38.1, JP39.1, R28.2
DOUT19: JP40.1, JP41.1, R29.2
DOUT20: JP42.1, JP43.1, R30.2
DOUT21: JP44.1, JP45.1, R31.2
DOUT22: JP46.1, JP47.1, R32.2
DOUT23: JP48.1, JP49.1, JP50.1, R33.2
DOUT24: JP51.1, JP52.1, JP53.1, R34.2
DOUT25: JP54.1, JP55.1, JP56.1, R35.2
DOUT26: JP57.1, JP58.1, JP59.1, R36.2
DOUT27: JP60.1, JP61.1, JP62.1, R37.2
DOUT28: JP63.1, JP64.1, JP65.1, R38.2
DOUT29: JP66.1, JP67.1, JP68.1, R39.2
GND: C1.1, D1.3, J1.2, J1.4, J2.2, J2.4, J4.2, J4.4
GND1: C2.1, D2.3, J5.2, J5.4, J6.2, J6.4, J7.2, J7.4, J8.2, J8.4
GND2: ATMEGA32U4.5, ATMEGA32U4.15, ATMEGA32U4.23, ATMEGA32U4.33, ATMEGA32U4.35, ATMEGA32U4.43, C3.1, C4.1, C5.2, C6.2, C7.1, C8.C, C9.C, C10.2, C11.C, C13.C, J3.GND, J9.2, J9.4, J10.2, J10.4, J11.2, J11.4, J12.2, J12.4, J13.2, J13.4, J14.2, J14.4, J15.2, J15.4, J16.2, J16.4, J17.2, J17.4, J18.2, J18.4, PRG.6, RESET.1
GND3: C12.1, D4.3, J19.2, J19.4, J20.2, J20.4, J21.2, J21.4
GND4: C14.1, D5.3, J22.2, J22.4, J23.2, J23.4, J24.2, J24.4
GND5: C15.1, D6.3, J25.2, J25.4, J26.2, J26.4, J27.2, J27.4
GND6: C16.1, D7.3, J28.2, J28.4, J29.2, J29.4, J30.2, J30.4
GND7: C17.1, D8.3, J31.2, J31.4, J32.2, J32.4, J33.2, J33.4
GND8: C18.1, D9.3, J34.2, J34.4, J35.2, J35.4, J36.2, J36.4
GND9: C19.1, D10.3, J37.2, J37.4, J38.2, J38.4, J39.2, J39.4
GND10: C20.1, D11.3, J40.2, J40.4, J41.2, J41.4, J42.2, J42.4
GND11: C21.1, D12.3, J43.2, J43.4, J44.2, J44.4, J45.2, J45.4
GND12: C22.1, D13.3, J46.2, J46.4, J47.2, J47.4, J48.2, J48.4
GND13: C23.1, D14.3, J49.2, J49.4, J50.2, J50.4, J51.2, J51.4
GND14: C24.1, D15.3, J52.2, J52.4, J53.2, J53.4, J54.2, J54.4
GND15: C25.1, D16.3, J55.2, J55.4, J56.2, J56.4, J57.2, J57.4
GND16: C26.1, D17.3, J58.2, J58.4, J59.2, J59.4, J60.2, J60.4
GND17: C27.1, D18.3, J61.2, J61.4, J62.2, J62.4, J63.2, J63.4
GND18: C28.1, D19.3, J64.2, J64.4, J65.2, J65.4, J66.2, J66.4
GND19: C29.1, D20.3, J67.2, J67.4, J68.2, J68.4, J69.2, J69.4
GND20: C30.1, D21.3, J70.2, J70.4, J71.2, J71.4, J72.2, J72.4
GND21: C31.1, D22.3, J73.2, J73.4, J74.2, J74.4, J75.2, J75.4
GND22: C32.1, D23.3, J76.2, J76.4, J77.2, J77.4, J78.2, J78.4
GND23: C33.1, D24.3, J79.2, J79.4, J80.2, J80.4, J81.2, J81.4
GND24: C34.1, D25.3, J82.2, J82.4, J83.2, J83.4, J84.2, J84.4, J85.2, J85.4
GND25: C35.1, D26.3, J86.2, J86.4, J87.2, J87.4, J88.2, J88.4, J89.2, J89.4
GND26: C36.1, D27.3, J90.2, J90.4, J91.2, J91.4, J92.2, J92.4, J93.2, J93.4
GND27: C37.1, D28.3, J94.2, J94.4, J95.2, J95.4, J96.2, J96.4, J97.2, J97.4
GND28: C38.1, D29.3, J98.2, J98.4, J99.2, J99.4, J100.2, J100.4, J101.2, J101.4
GND29: C39.1, D30.3, J102.2, J102.4, J103.2, J103.4, J104.2, J104.4, J105.2, J105.4
GND30: C40.1, D31.3, J106.2, J106.4, J107.2, J107.4, J108.2, J108.4, J109.2, J109.4
MISO: ATMEGA32U4.11, PRG.1
MOSI: ATMEGA32U4.10, PRG.4
unnamed: J1.3, JP2.2
unnamed: J2.3, JP1.2
unnamed: D1.2, R1.1
unnamed: J7.3, JP4.2
unnamed: J6.3, JP3.2
unnamed: J5.3, JP5.2
unnamed: D2.2, R2.1
unnamed: ATMEGA32U4.16, C6.1, Y1.1
unnamed: ATMEGA32U4.17, C5.1, Y1.2
unnamed: J3.D-, R7.2
unnamed: J3.D+, R5.2
unnamed: D3.-, R6.2
unnamed: J9.3, J10.3, R4.2
unnamed: J11.3, J12.3, R8.2
unnamed: J13.3, J14.3, R9.2
unnamed: J15.3, J16.3, R10.2
unnamed: J17.3, J18.3, R11.2
unnamed: J20.3, JP7.2
unnamed: D4.2, R12.1
unnamed: J21.3, JP6.2
unnamed: J23.3, JP9.2
unnamed: D5.2, R13.1
unnamed: J24.3, JP8.2
unnamed: J26.3, JP11.2
unnamed: D6.2, R14.1
unnamed: J27.3, JP10.2
unnamed: J29.3, JP13.2
unnamed: D7.2, R15.1
unnamed: J30.3, JP12.2
unnamed: J32.3, JP15.2
unnamed: D8.2, R16.1
unnamed: J33.3, JP14.2
unnamed: J35.3, JP17.2
unnamed: D9.2, R17.1
unnamed: J36.3, JP16.2
unnamed: J38.3, JP19.2
unnamed: D10.2, R18.1
unnamed: J39.3, JP18.2
unnamed: J41.3, JP21.2
unnamed: D11.2, R19.1
unnamed: J42.3, JP20.2
unnamed: J44.3, JP23.2
unnamed: D12.2, R20.1
unnamed: J45.3, JP22.2
unnamed: J47.3, JP25.2
unnamed: D13.2, R21.1
unnamed: J48.3, JP24.2
unnamed: J50.3, JP27.2
unnamed: D14.2, R22.1
unnamed: J51.3, JP26.2
unnamed: J53.3, JP29.2
unnamed: D15.2, R23.1
unnamed: J54.3, JP28.2
unnamed: J56.3, JP31.2
unnamed: D16.2, R24.1
unnamed: J57.3, JP30.2
unnamed: J59.3, JP33.2
unnamed: D17.2, R25.1
unnamed: J60.3, JP32.2
unnamed: J62.3, JP35.2
unnamed: D18.2, R26.1
unnamed: J63.3, JP34.2
unnamed: J65.3, JP37.2
unnamed: D19.2, R27.1
unnamed: J66.3, JP36.2
unnamed: J68.3, JP39.2
unnamed: D20.2, R28.1
unnamed: J69.3, JP38.2
unnamed: J71.3, JP41.2
unnamed: D21.2, R29.1
unnamed: J72.3, JP40.2
unnamed: J74.3, JP43.2
unnamed: D22.2, R30.1
unnamed: J75.3, JP42.2
unnamed: J77.3, JP45.2
unnamed: D23.2, R31.1
unnamed: J78.3, JP44.2
unnamed: J80.3, JP47.2
unnamed: D24.2, R32.1
unnamed: J81.3, JP46.2
unnamed: J84.3, JP49.2
unnamed: J83.3, JP48.2
unnamed: J82.3, JP50.2
unnamed: D25.2, R33.1
unnamed: J88.3, JP52.2
unnamed: J87.3, JP51.2
unnamed: J86.3, JP53.2
unnamed: D26.2, R34.1
unnamed: J92.3, JP55.2
unnamed: J91.3, JP54.2
unnamed: J90.3, JP56.2
unnamed: D27.2, R35.1
unnamed: J96.3, JP58.2
unnamed: J95.3, JP57.2
unnamed: J94.3, JP59.2
unnamed: D28.2, R36.1
unnamed: J100.3, JP61.2
unnamed: J99.3, JP60.2
unnamed: J98.3, JP62.2
unnamed: D29.2, R37.1
unnamed: J104.3, JP64.2
unnamed: J103.3, JP63.2
unnamed: J102.3, JP65.2
unnamed: D30.2, R38.1
unnamed: J108.3, JP67.2
unnamed: J107.3, JP66.2
unnamed: J106.3, JP68.2
unnamed: D31.2, R39.1
RESET: ATMEGA32U4.13, PRG.5, R3.1, RESET.2
SCK: ATMEGA32U4.9, PRG.3
TXLED: ATMEGA32U4.22, R6.1
UCAP: ATMEGA32U4.6, C7.2
VIN: C1.2, D1.1, J1.1, J1.5, J2.1, J2.5, J4.1, J4.5
VIN1: C2.2, D2.1, J5.1, J5.5, J6.1, J6.5, J7.1, J7.5, J8.1, J8.5
VIN2: C12.2, D4.1, J19.1, J19.5, J20.1, J20.5, J21.1, J21.5
VIN3: C14.2, D5.1, J22.1, J22.5, J23.1, J23.5, J24.1, J24.5
VIN4: C15.2, D6.1, J25.1, J25.5, J26.1, J26.5, J27.1, J27.5
VIN5: C16.2, D7.1, J28.1, J28.5, J29.1, J29.5, J30.1, J30.5
VIN6: C17.2, D8.1, J31.1, J31.5, J32.1, J32.5, J33.1, J33.5
VIN7: C18.2, D9.1, J34.1, J34.5, J35.1, J35.5, J36.1, J36.5
VIN8: C19.2, D10.1, J37.1, J37.5, J38.1, J38.5, J39.1, J39.5
VIN9: C20.2, D11.1, J40.1, J40.5, J41.1, J41.5, J42.1, J42.5
VIN10: C21.2, D12.1, J43.1, J43.5, J44.1, J44.5, J45.1, J45.5
VIN11: C22.2, D13.1, J46.1, J46.5, J47.1, J47.5, J48.1, J48.5
VIN12: C23.2, D14.1, J49.1, J49.5, J50.1, J50.5, J51.1, J51.5
VIN13: C24.2, D15.1, J52.1, J52.5, J53.1, J53.5, J54.1, J54.5
VIN14: C25.2, D16.1, J55.1, J55.5, J56.1, J56.5, J57.1, J57.5
VIN15: C26.2, D17.1, J58.1, J58.5, J59.1, J59.5, J60.1, J60.5
VIN16: C27.2, D18.1, J61.1, J61.5, J62.1, J62.5, J63.1, J63.5
VIN17: C28.2, D19.1, J64.1, J64.5, J65.1, J65.5, J66.1, J66.5
VIN18: C29.2, D20.1, J67.1, J67.5, J68.1, J68.5, J69.1, J69.5
VIN19: C30.2, D21.1, J70.1, J70.5, J71.1, J71.5, J72.1, J72.5
VIN20: C31.2, D22.1, J73.1, J73.5, J74.1, J74.5, J75.1, J75.5
VIN21: C32.2, D23.1, J76.1, J76.5, J77.1, J77.5, J78.1, J78.5
VIN22: C33.2, D24.1, J79.1, J79.5, J80.1, J80.5, J81.1, J81.5
VIN23: C34.2, D25.1, J82.1, J82.5, J83.1, J83.5, J84.1, J84.5, J85.1, J85.5
VIN24: C35.2, D26.1, J86.1, J86.5, J87.1, J87.5, J88.1, J88.5, J89.1, J89.5
VIN25: C36.2, D27.1, J90.1, J90.5, J91.1, J91.5, J92.1, J92.5, J93.1, J93.5
VIN26: C37.2, D28.1, J94.1, J94.5, J95.1, J95.5, J96.1, J96.5, J97.1, J97.5
VIN27: C38.2, D29.1, J98.1, J98.5, J99.1, J99.5, J100.1, J100.5, J101.1, J101.5
VIN28: C39.2, D30.1, J102.1, J102.5, J103.1, J103.5, J104.1, J104.5, J105.1, J105.5
VIN29: C40.2, D31.1, J106.1, J106.5, J107.1, J107.5, J108.1, J108.5, J109.1, J109.5

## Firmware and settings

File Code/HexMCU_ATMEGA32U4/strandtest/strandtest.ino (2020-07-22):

///////////////////////////////////////////////////////////
// Trixel LED HexagonMCU atmgea32u4 - arkadiraf@gmail.com //
//    Strand test based on adafruit code - 11/04/2018    //
///////////////////////////////////////////////////////////
// Genuino Micro bootloader             //
// high_fuses=0xd8                      //
// low_fuses=0xff                       //
// extended_fuses=0xcb                  //
// caterina/Caterina-Genuino-Micro.hex  //
//////////////////////////////////////////

///////////////
// Libraries //
///////////////
#include "Adafruit_NeoPixel.h"
///////////////
// Variables //
///////////////
// neopixel LED Pin
#define STRIP_PIN_1 11
#define STRIP_PIN_2 2
#define STRIP_PIN_3 8
#define STRIP_PIN_4 5
#define STRIP_PIN_5 7

#define NUM_LEDS_1 4
#define NUM_LEDS_2 4
#define NUM_LEDS_3 10
#define NUM_LEDS_4 4
#define NUM_LEDS_5 4

uint8_t brightness=75;
// Parameter 1 = number of pixels in strip
// Parameter 2 = Arduino pin number (most are valid)
// Parameter 3 = pixel type flags, add together as needed:
//   NEO_KHZ800  800 KHz bitstream (most NeoPixel products w/WS2812 LEDs)
//   NEO_KHZ400  400 KHz (classic 'v1' (not v2) FLORA pixels, WS2811 drivers)
//   NEO_GRB     Pixels are wired for GRB bitstream (most NeoPixel products)
//   NEO_RGB     Pixels are wired for RGB bitstream (v1 FLORA pixels, not v2)
//   NEO_RGBW    Pixels are wired for RGBW bitstream (NeoPixel RGBW products)
Adafruit_NeoPixel strip_1 = Adafruit_NeoPixel(NUM_LEDS_1, STRIP_PIN_1, NEO_GRB + NEO_KHZ800);
Adafruit_NeoPixel strip_2 = Adafruit_NeoPixel(NUM_LEDS_2, STRIP_PIN_2, NEO_GRB + NEO_KHZ800);
Adafruit_NeoPixel strip_3 = Adafruit_NeoPixel(NUM_LEDS_3, STRIP_PIN_3, NEO_GRB + NEO_KHZ800);
Adafruit_NeoPixel strip_4 = Adafruit_NeoPixel(NUM_LEDS_4, STRIP_PIN_4, NEO_GRB + NEO_KHZ800);
Adafruit_NeoPixel strip_5 = Adafruit_NeoPixel(NUM_LEDS_5, STRIP_PIN_5, NEO_GRB + NEO_KHZ800);
void setup() {
  Serial.begin(57600); //This pipes to the serial monitor
  strip_1.begin();
  strip_1.show(); // Initialize all pixels to 'off'
  strip_2.begin();
  strip_2.show(); // Initialize all pixels to 'off'
  strip_3.begin();
  strip_3.show(); // Initialize all pixels to 'off'
  strip_4.begin();
  strip_4.show(); // Initialize all pixels to 'off'
  strip_5.begin();
  strip_5.show(); // Initialize all pixels to 'off'
}

void loop() {
  static int Status = 0;
  Serial.println("Hello world");  // Print "Hello World" to the Serial Monitor
  TXLED0; //TX LED is not tied to a normally controlled pin
  Status = !Status;
  Status == 1 ? TXLED1 : TXLED0;

//  // run Pixel effects
//  Status == 1 ? strip_1.setBrightness(255) : strip_1.setBrightness(255);
//  Status == 1 ? strip_2.setBrightness(255) : strip_2.setBrightness(255);
//  Status == 1 ? strip_3.setBrightness(255) : strip_3.setBrightness(255);
//  Status == 1 ? strip_4.setBrightness(255) : strip_4.setBrightness(255);
//  Status == 1 ? strip_5.setBrightness(255) : strip_5.setBrightness(255);
  strip_1.setBrightness(brightness);
  strip_2.setBrightness(brightness);
  strip_3.setBrightness(brightness);
  strip_4.setBrightness(brightness);
  strip_5.setBrightness(brightness);
  //Status==1 ? rainbow(20) : rainbow(2);
  //Status==1 ? rainbowCycle(20) : rainbowCycle(2);
  rainbowCycle(5);
}

// Adafruit NeoPixel Example functions //
// Fill the dots one after the other with a color
void colorWipe(uint32_t c, uint8_t wait) {
  for (uint16_t i = 0; i < strip_1.numPixels(); i++) {
    strip_1.setPixelColor(i, c);
    strip_1.show();
    delay(wait);
  }
}

void rainbow(uint8_t wait) {
  uint16_t i, j;

  for (j = 0; j < 256; j++) {
    for (i = 0; i < strip_1.numPixels(); i++) {
      strip_1.setPixelColor(i, Wheel((i + j) & 255));
    }
    strip_1.show();
    delay(wait);
  }
}

// Slightly different, this makes the rainbow equally distributed throughout
void rainbowCycle(uint8_t wait) {
  uint16_t i, j;

  for (j = 0; j < 256 * 5; j++) { // 5 cycles of all colors on wheel
    for (i = 0; i < strip_1.numPixels(); i++) {
      strip_1.setPixelColor(i, Wheel(((i * 256 / strip_1.numPixels()) + j) & 255));
    }
    for (i = 0; i < strip_2.numPixels(); i++) {
      strip_2.setPixelColor(i, Wheel(((i * 256 / strip_2.numPixels()) + j + 25) & 255));
    }
    for (i = 0; i < strip_3.numPixels(); i++) {
      strip_3.setPixelColor(i, Wheel(((i * 256 / strip_3.numPixels()) + j + 50) & 255));
    }
    for (i = 0; i < strip_4.numPixels(); i++) {
      strip_4.setPixelColor(i, Wheel(((i * 256 / strip_4.numPixels()) + j + 75) & 255));
    }
    for (i = 0; i < strip_5.numPixels(); i++) {
      strip_5.setPixelColor(i, Wheel(((i * 256 / strip_5.numPixels()) + j + 100) & 255));
    }
    strip_1.show();
    strip_2.show();
    strip_3.show();
    strip_4.show();
    strip_5.show();
    delay(wait);
  }
}

//Theatre-style crawling lights.
void theaterChase(uint32_t c, uint8_t wait) {
  for (int j = 0; j < 10; j++) { //do 10 cycles of chasing
    for (int q = 0; q < 3; q++) {
      for (uint16_t i = 0; i < strip_1.numPixels(); i = i + 3) {
        strip_1.setPixelColor(i + q, c);  //turn every third pixel on
      }
      strip_1.show();

      delay(wait);

      for (uint16_t i = 0; i < strip_1.numPixels(); i = i + 3) {
        strip_1.setPixelColor(i + q, 0);      //turn every third pixel off
      }
    }
  }
}

//Theatre-style crawling lights with rainbow effect
void theaterChaseRainbow(uint8_t wait) {
  for (int j = 0; j < 256; j++) {   // cycle all 256 colors in the wheel
    for (int q = 0; q < 3; q++) {
      for (uint16_t i = 0; i < strip_1.numPixels(); i = i + 3) {
        strip_1.setPixelColor(i + q, Wheel( (i + j) % 255)); //turn every third pixel on
      }
      strip_1.show();

      delay(wait);

      for (uint16_t i = 0; i < strip_1.numPixels(); i = i + 3) {
        strip_1.setPixelColor(i + q, 0);      //turn every third pixel off
      }
    }
  }
}

// Input a value 0 to 255 to get a color value.
// The colours are a transition r - g - b - back to r.
uint32_t Wheel(byte WheelPos) {
  WheelPos = 255 - WheelPos;
  if (WheelPos < 85) {
    return strip_1.Color(255 - WheelPos * 3, 0, WheelPos * 3);
  }
  if (WheelPos < 170) {
    WheelPos -= 85;
    return strip_1.Color(0, WheelPos * 3, 255 - WheelPos * 3);
  }
  WheelPos -= 170;
  return strip_1.Color(WheelPos * 3, 255 - WheelPos * 3, 0);
}

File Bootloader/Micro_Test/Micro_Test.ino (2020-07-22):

// the setup function runs once when you press reset or power the board
void setup() {
  // initialize digital pin LED_BUILTIN as an output.
  Serial.begin(9600); //This pipes to the serial monitor
  Serial1.begin(9600); //This is the UART, pipes to sensors attached to board
}

// the loop function runs over and over again forever
void loop() {
  Serial.println("Hello world");  // Print "Hello World" to the Serial Monitor
  Serial1.println("Hello!");  // Print "Hello!" over hardware UART
  TXLED0; //TX LED is not tied to a normally controlled pin
  delay(100);              // wait for a second
  TXLED1;
  delay(1000);              // wait for a second
}

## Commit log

2017-03-26 First commit
    Eagle design files uploaded
    [Hexagonal_MCU_V02.brd, Hexagonal_MCU_V02.sch, Simple_MCU_V01.brd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]
2018-04-11 Added sample code to hexagon mcu
2018-04-12 Panel updated
    [Hexagonal_MCU.brd, Hexagonal_MCU.dxf, Hexagonal_MCU.sch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]
2018-05-25 Latest versions update
    [Hexagonal_MCU.brd, Hexagonal_MCU.dxf, Hexagonal_MCU.sch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]
2018-07-26 Latest large panel designes
    [2018-04-14T14_55_40.csv, Hexagonal_MCU.brd, Hexagonal_MCU.csv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]

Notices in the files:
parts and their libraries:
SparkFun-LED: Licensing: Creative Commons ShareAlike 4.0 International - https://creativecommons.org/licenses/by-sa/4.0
